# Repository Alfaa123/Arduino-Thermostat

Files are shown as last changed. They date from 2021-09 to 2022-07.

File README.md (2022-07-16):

# Arduino-Thermostat

This is a project to create a Arduino (or Arduino compatible) powered home thermostat. Version 2 PCB schematic and design is complete.

# Electrical Design

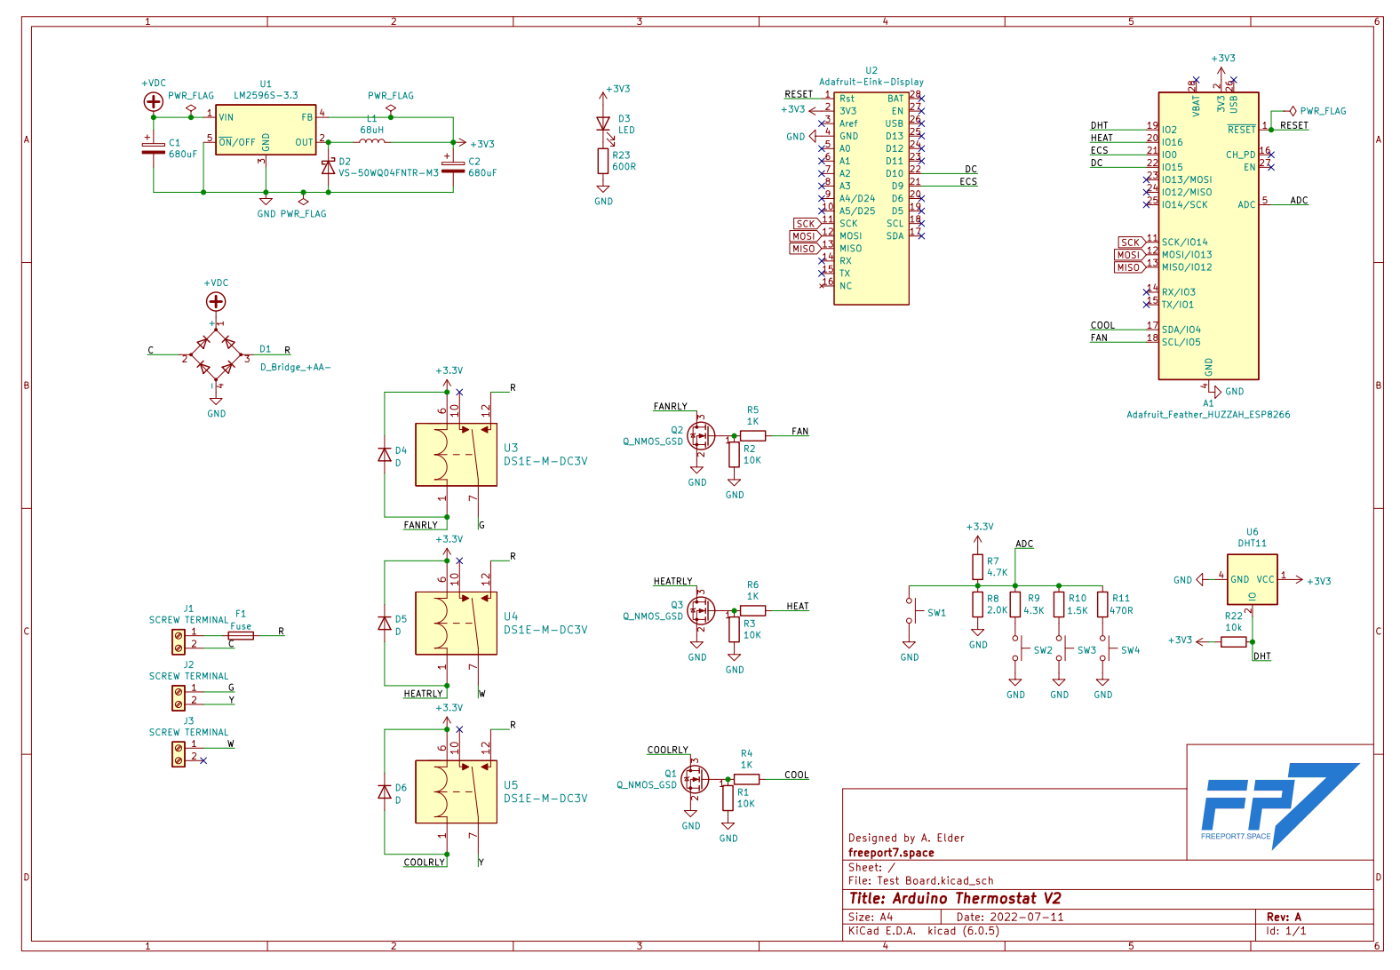
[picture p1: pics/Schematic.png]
Schematic


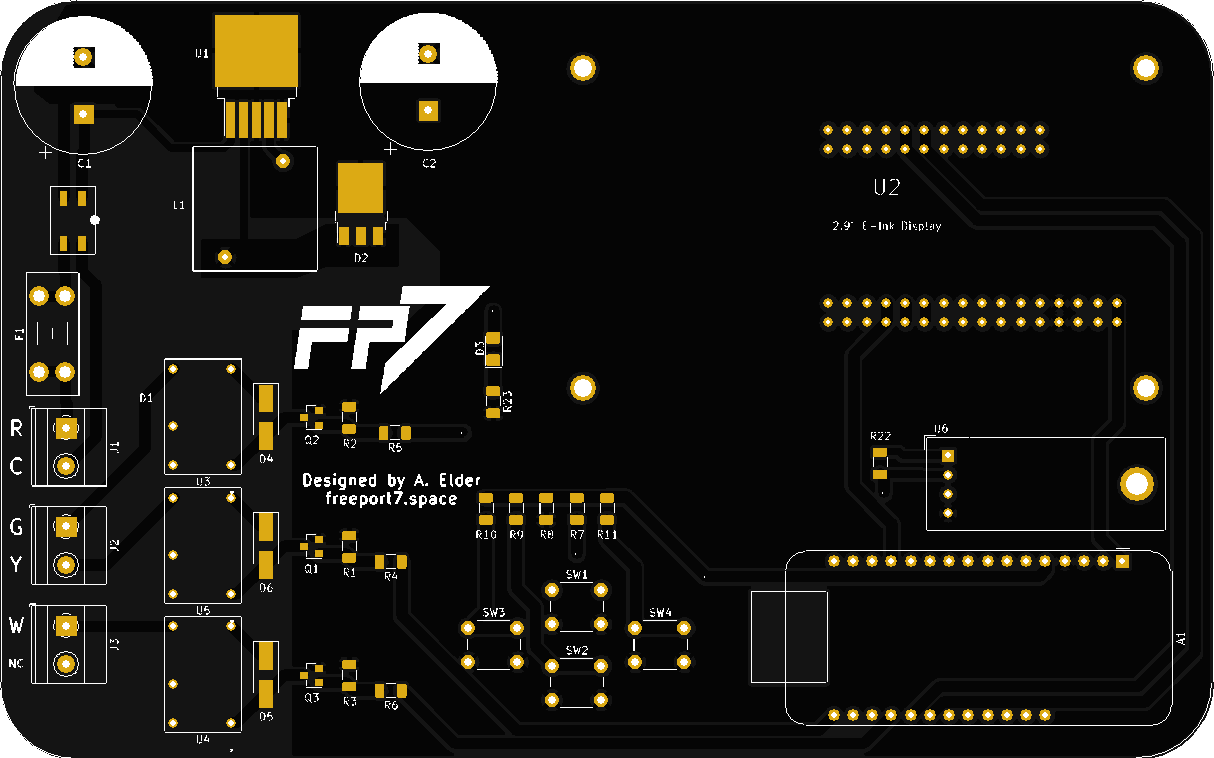
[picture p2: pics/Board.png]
Board


Version 2 has been updated and upgraded to use many SMD components. The board has shrunk, extra protections added and lots of the lessons learned from V1 were implemented as changes to V2.

## Power Section

This takes the 24v AC from the air handler transformer and rectifies it to create a high voltage DC bus. This is then smoothed and an LM2596 is used as a switching regulator to create a 3.3v supply.

Power for the feather is supplied via the 3.3v pin from the onboard voltage regulator.

The regulator can handle up to 3a of current and would be accurately described as "way overkill" for the power requirements of the low voltage section of this board. However, the LM2596 regulators are so simple and easy to effectively use (thanks TI!) that it was worth the extra cost to just have something "easy."

Because the circuitry in the air handler requires the relays to be switched on with the supplied 24v AC, it is routed down the board to supply the common terminal of the three main relays.

## Relay Drive Section

In order to drive the relays, small logic level MOSFETS are utilized with the feather board outputs acting as gate drivers for the three MOSFETs. The current requirements for the selected relays are very low and can easily be sunk by the selected MOSFETs.

## Inputs and Outputs

An Adafruit Feather HUZZAH ESP8266 will be used to run the thermostat. This was selected because it was cheap, easy to work with and included a WiFi stack (allowing for some internet connected thermostat features in the future). One limitation of the ESP8266 is the extremely limited IO compared to the Arduino Nano of the V1 design. This lead to lots of design challanges, including the use of the onboard ADC for ladder buttons to save IO.

The central feature of the V2 design is the inclusion of a 2.9 inch e-ink display instead of a standard LCD. This high resolution, low power display will be ideal for a thermostat as the display needs minimal updates during normal usage.

## Physical Outline

The physical outline of the board was designed to mimic my current thermostat. No mounting holes are included in the V2 design due to the success of the board edge mount that was used on the V1 design.

## Lessons Learned for V2

- ~~Arduino placement needs to be revised. Currently plugging in the USB cable is impossible without bending a cable and potentially damaging the Arduino. This is the biggest mistake.~~ **fixed on V2 design. USB connector points toward the board edge and is easy to access**
- ~~Screw terminal placement needs to be revised. Currently with the massive spacing, it required me to trim a lot of the insulation off of the 5 conductor cable in order to spread the wires out far enough to reach.~~ **fixed on V2 design. Screw terminals were moved much closer together and should make wiring the thermostat much easier**
- ~~More markings on the front of the PCB to show which screw terminal does what. Currently it requires me to open the schematic and board files to correctly wire the thermostat.~~ **fixed on V2 design. Board markings on the silkscreen should make wiring the thermostat much easier.**
- ~~More work should be done to minimize footprint. Currently, the thermostat is physically very large.~~ **fixed on V2 design. Board outline has shrunk to around 60% of the original size.**
- ~~A larger screen would be nice to fit more information. A dot matrix or OLED would be best.~~ **fixed on V2 design. e-ink display selected as high resolution and low power display.**
- ~~Smaller regulator section and relays would go a long way to making the board shrink.~~ **unchanged on V2 design. However, the capacitors were revised with shorter, higher quality parts, the regulator was changed to a surface mount version and the diode and inductor were swapped with physically smaller versions.**

# Programming

No V2 programming has been written yet.

## Required Libraries

TBD once V2 programming is underway

## Planned Future Development

- PID control or other method for better temperature control.
- Humidistat control mode
- Adjustable circ fan frequency
- Better menu system
- Filtering on the temperature sensor to prevent rapid cycling
- Cycling time limit to prevent compressor damage

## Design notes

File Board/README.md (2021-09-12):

# Arduino-Thermostat

This is a project to create a arduino powered home thermostat. Currently the project is in the electrical design stage. Version 1 PCB schematic and design is complete.

# Electrical Design

Schematic

Board

The entire project was designed to be through hole for ease of assembly and troubleshooting. Perhaps in the future, a SMD version with a smaller footprint can be made once the electrical design is finalized.

## Power Section

This takes the 24v AC from the air handler transformer and rectifies it to create a higher voltage DC bus. This is then smoothed and an LM2596 is used as a switching regulator to create a 5.0v supply.

Power for the arduino is supplied via the 5v pin from the onboard voltage regulator.

The regulator can handle upto 3a of current and would be accurately described as "way overkill" for the power requirements of the low voltage section of this board. Once V1 is confirmed to be working, a redesign will be carried out that will allow a lower BOM cost and a physical design shrink.

Because the circuitry in the air handler requires the relays to be switched on with the supplied 24v AC, it is routed down the board to supply the common terminal of the three main relays.

## Relay Driver

A L293D Bipolar Motor Driver was chosen because it was readily available in DIP format, worked for the voltages required, had logic level inputs and had built in flyback diodes that allowed for less physical space usage at the expense of a higher BOM cost.

Additionally, due to the extra available output, the supply for the LCD backlight is switched with output 4.

## Inputs and Outputs

An arduino nano will be used to run the thermostat, ample GPIO meant that each physical button could have it's own DIO pin. Additionally, the LCD was able to be run directly in 4 bit parallel mode allowing for lower BOM cost and simpler electrical design.

The DHT11 may be swapped out with a DHT22 as they have the same footprint and the DHT 22 has a wider range of measurement.

## Physical Outline

The physical outline of the board was designed to mimic my current thermostat. 4 mounting holes were provided to allow for either wall mounting or a case.

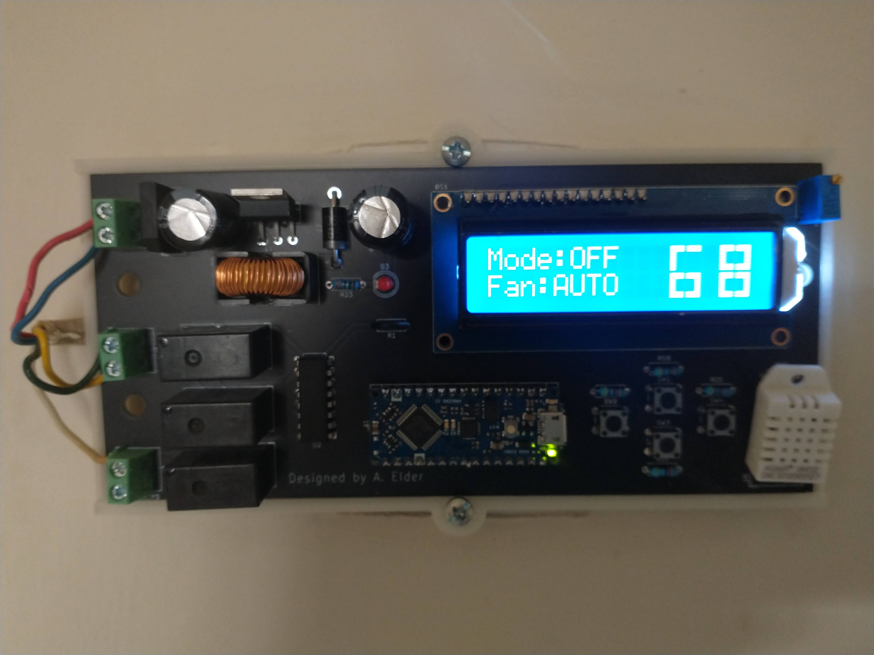
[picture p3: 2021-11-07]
pics/Working.jpg

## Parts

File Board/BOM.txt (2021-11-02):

https://www.digikey.com/en/products/detail/te-connectivity-amp-connectors/796911-3/2223900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

https://www.digikey.com/en/products/detail/te-connectivity-amp-connectors/796911-2/14786015

https://www.digikey.com/en/products/detail/apem-inc/MJTP1230/1798037

https://www.digikey.com/en/products/detail/microchip-technology/lm2575-5-0bt/1027650

https://www.digikey.com/en/products/detail/bourns-inc/2100LL-331-H-RC/725965

https://www.digikey.com/en/products/detail/stmicroelectronics/STPS5L60/2864639

https://www.digikey.com/en/products/detail/panasonic-electronic-components/EEU-FC1C101H/6109530

https://www.digikey.com/en/products/detail/panasonic-electronic-components/EEU-FC1H221B/6109552

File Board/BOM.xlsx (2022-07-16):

Description | Qty | Link
Relay | 3 | https://www.digikey.com/en/products/detail/panasonic-electric-works/DS1E-S-DC3V/413288
2 Position Screw Terminal | 3 | https://www.digikey.com/en/products/detail/phoenix-contact/5442206/4390264
Voltage Regulator | 1 | https://www.digikey.com/en/products/detail/texas-instruments/LM2596S-3-3/3701219
Input/Output Cap | 2 | https://www.digikey.com/en/products/detail/panasonic-electronic-components/EEU-FC1J681S/356177
Schottky Diode | 1 | https://www.digikey.com/en/products/detail/vishay-general-semiconductor-diodes-division/VS-50WQ04FNTR-M3/4933731
Inductor 68 uH | 1 | https://www.digikey.com/en/products/detail/pulse-electronics-power/PE-53830NL/2266003
5mm LED | 1 | Sourced Locally
220R 1/4w THT Resistor | 4 | Sourced Locally
10K 1/4w THT Resistor | 4 | Sourced Locally
Rectifier | 1 | https://www.digikey.com/en/products/detail/smc-diode-solutions/KMB26S/7898343
Logic Level FET | 3 | https://www.digikey.com/en/products/detail/infineon-technologies/BSS806NH6327XTSA1/2783472
Header Pins for Display | 2 | https://www.digikey.com/en/products/detail/amphenol-cs-fci/67996-416HLF/1878538
16 Pin Header For Feather | 1 | https://www.digikey.com/en/products/detail/sullins-connector-solutions/PPTC161LFBN-RC/810154
12 Pin Header For Feather | 1 | https://www.digikey.com/en/products/detail/sullins-connector-solutions/PPTC121LFBN-RC/807231
e-Ink Display | 1 | https://www.adafruit.com/product/4777
MCU | 2 | https://www.adafruit.com/product/2821
Flyback Diodes | 3 | https://www.digikey.com/en/products/detail/smc-diode-solutions/S1G/6022594
LED | 1 | https://www.digikey.com/en/products/detail/everlight-electronics-co-ltd/QTLP650D4TR/2675910
Buttons | 4 | https://www.digikey.com/en/products/detail/cui-devices/TS02-66-60-BK-160-SCR-D/15634259
Fuse Holder | 1 | https://www.digikey.com/en/products/detail/keystone-electronics/3568/2137306
Fuse | 1 | https://www.digikey.com/en/products/detail/eaton-bussmann-electrical-division/BK-ATM-3/264847

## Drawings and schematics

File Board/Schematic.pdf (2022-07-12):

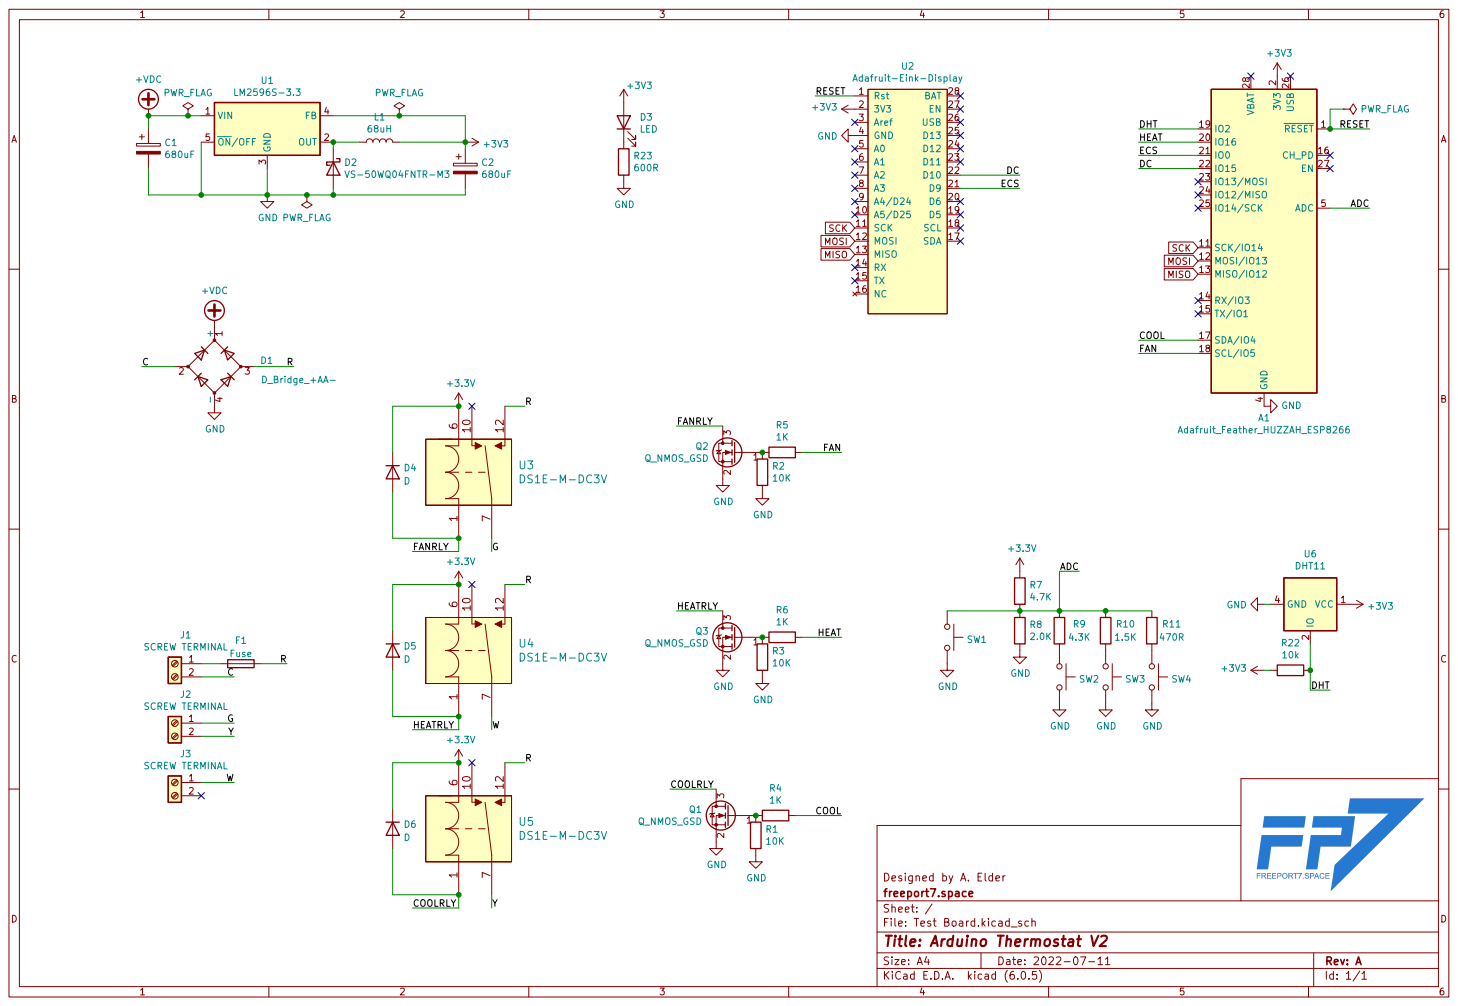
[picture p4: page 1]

2 GND 4 U6 DHT11 D2VS-50WQ04FNTR-M3 ~{RESET} 1 SCK/IO14 11 MOSI/IO13 12 MISO/IO12 13 RX/IO3 14 TX/IO1 15 CH_PD 16 SDA/IO4 17 SCL/IO5 18

SCK MOSI SCK MOSI MISO

File: Test Board.kicad_sch Sheet: / freeport7.space

Id: 1/1 Title: Arduino Thermostat V2

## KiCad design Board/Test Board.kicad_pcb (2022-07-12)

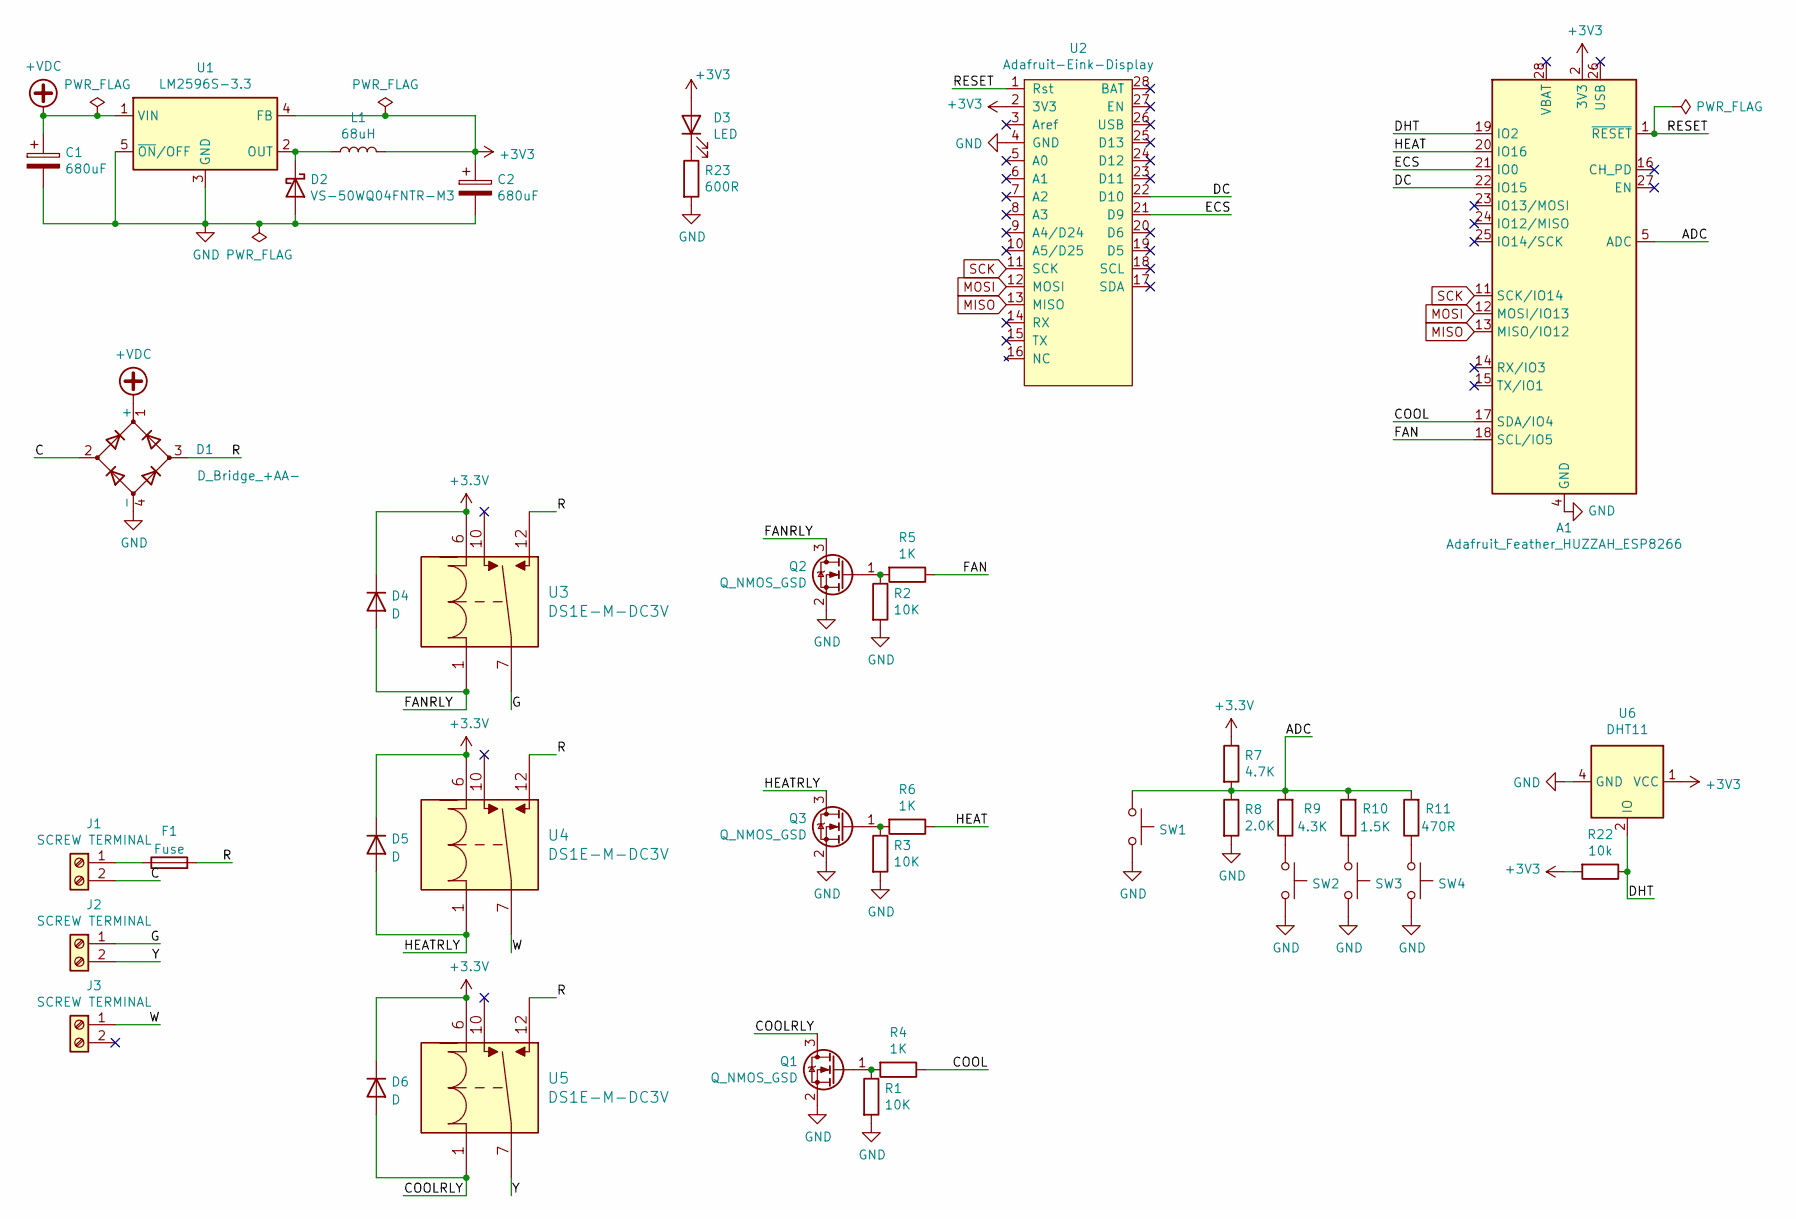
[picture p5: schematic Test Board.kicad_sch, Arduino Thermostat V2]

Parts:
A1: Adafruit_Feather_HUZZAH_ESP8266; Adafruit_Feather
C1, C2: 680uF; CP_Radial_D18.0mm_P7.50mm
D1: D_Bridge_+AA-; Diode Bridge 4-SMD
D2: VS-50WQ04FNTR-M3; TO-252-3_TabPin2
D3: LED; LED_1206_3216Metric_Pad1.42x1.75mm_HandSolder
D4, D5, D6: D; D_SMA_Handsoldering
F1: Fuse; Fuseholder_Blade_Mini_Keystone_3568
J1, J2, J3: SCREW TERMINAL; TerminalBlock_Phoenix_MKDS-1,5-2-5.08_1x02_P5.08mm_Horizont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
L1: 68uH; L_Radial_L16.1mm_W16.1mm_Px7.62mm_Py12.70mm_Pulse_LP-44
Q1, Q2, Q3: Q_NMOS_GSD; SOT-23
R1, R2, R3: 10K; R_1206_3216Metric
R4, R5, R6: 1K; R_1206_3216Metric
R7: 4.7K; R_1206_3216Metric
R8: 2.0K; R_1206_3216Metric
R9: 4.3K; R_1206_3216Metric
R10: 1.5K; R_1206_3216Metric
R11: 470R; R_1206_3216Metric
R22: 10k; R_1206_3216Metric
R23: 600R; R_1206_3216Metric
SW1, SW2, SW3, SW4: SW_Push; SW_PUSH_6mm_H5mm
U1: LM2596S-3.3; TO-263-5_TabPin3
U2: Adafruit-Eink-Display; Adafruit-eink-display
U3, U4, U5: DS1E-M-DC3V; DS1E-M-DC5V
U6: DHT11; DHT22-Horizontal

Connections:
+VDC: C1.1, D1.1 (+), U1.1 (VIN)
/ADC: A1.5 (ADC), R7.2, R8.1, R9.2, R10.2, R11.2, SW1.1
/C: D1.2, J1.2
/COOL: A1.17 (SDA/IO4), R4.1
/COOLRLY: D6.2 (A), Q1.3 (D), U5.1
/DC: A1.22 (IO15), U2.22 (D10)
/DHT: A1.19 (IO2), R22.1, U6.2 (IO)
/ECS: A1.21 (IO0), U2.21 (D9)
/FAN: A1.18 (SCL/IO5), R5.1
/FANRLY: D4.2 (A), Q2.3 (D), U3.1
/G: J2.1, U3.7
/HEAT: A1.20 (IO16), R6.1
/HEATRLY: D5.2 (A), Q3.3 (D), U4.1
/R: D1.3, F1.2, U3.12, U4.12, U5.12
/RESET: A1.1 (~RESET), U2.1 (Rst)
/W: J3.1, U4.7
/Y: J2.2, U5.7
GND: A1.4 (GND), C1.2, C2.2, D1.4 (-), D2.2 (A), Q1.2 (S), Q2.2 (S), Q3.2 (S), R1.2, R2.2, R3.2, R8.2, R23.2, SW1.2, SW2.2, SW3.2, SW4.2, U1.3 (GND), U1.5 (~ON/OFF), U2.4 (GND), U6.4 (GND)
MISO: A1.13 (MISO/IO12), U2.13 (MISO)
MOSI: A1.12 (MOSI/IO13), U2.12 (MOSI)
unnamed: D2.1 (K), L1.1, U1.2 (OUT)
unnamed: D3.1 (K), R23.1
unnamed: F1.1, J1.1
unnamed: Q1.1 (G), R1.1, R4.2
unnamed: Q2.1 (G), R2.1, R5.2
unnamed: Q3.1 (G), R3.1, R6.2
unnamed: R9.1, SW2.1
unnamed: R10.1, SW3.1
unnamed: R11.1, SW4.1
SCK: A1.11 (SCK/IO14), U2.11 (SCK)

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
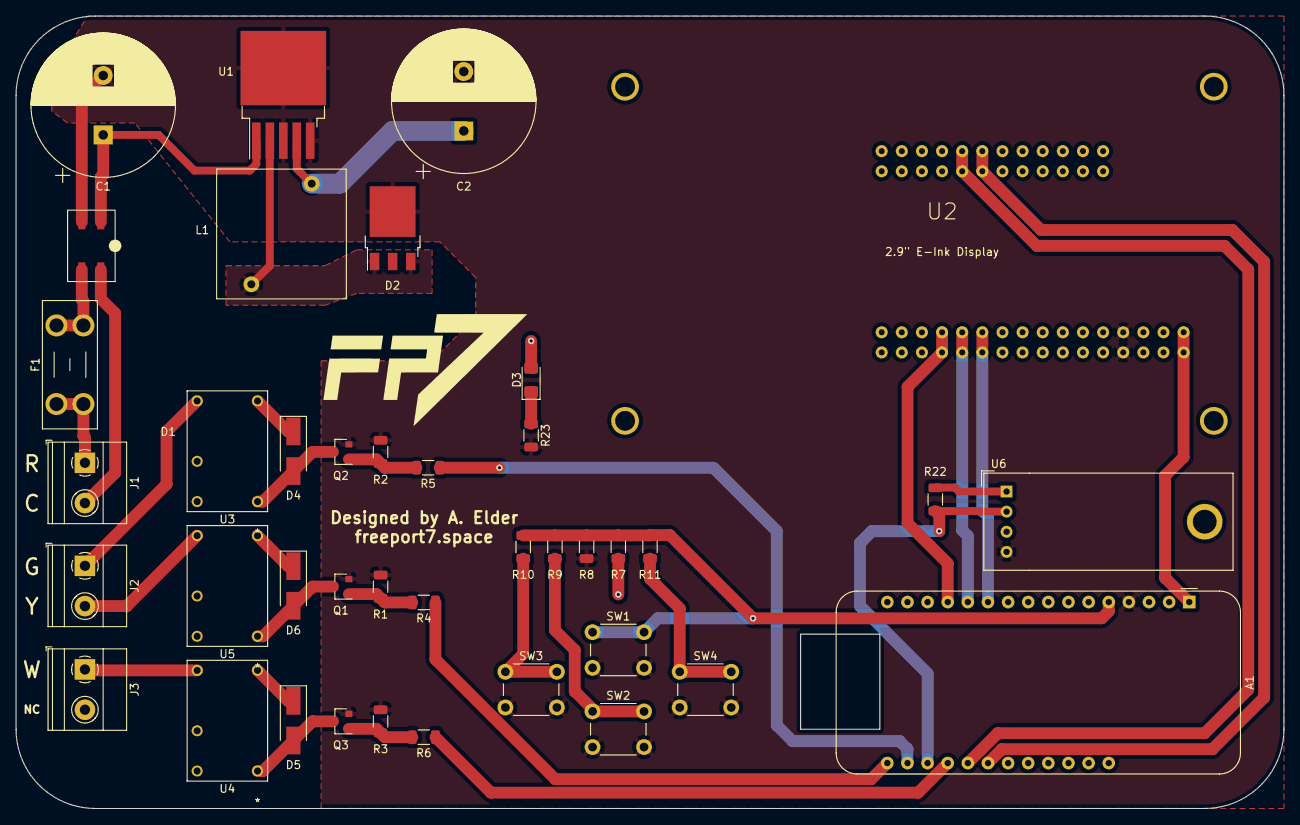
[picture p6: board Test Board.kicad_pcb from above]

Board: 2 copper layers, 160.0 x 100.0 mm, 40 parts (0 on the bottom side), 31 nets.

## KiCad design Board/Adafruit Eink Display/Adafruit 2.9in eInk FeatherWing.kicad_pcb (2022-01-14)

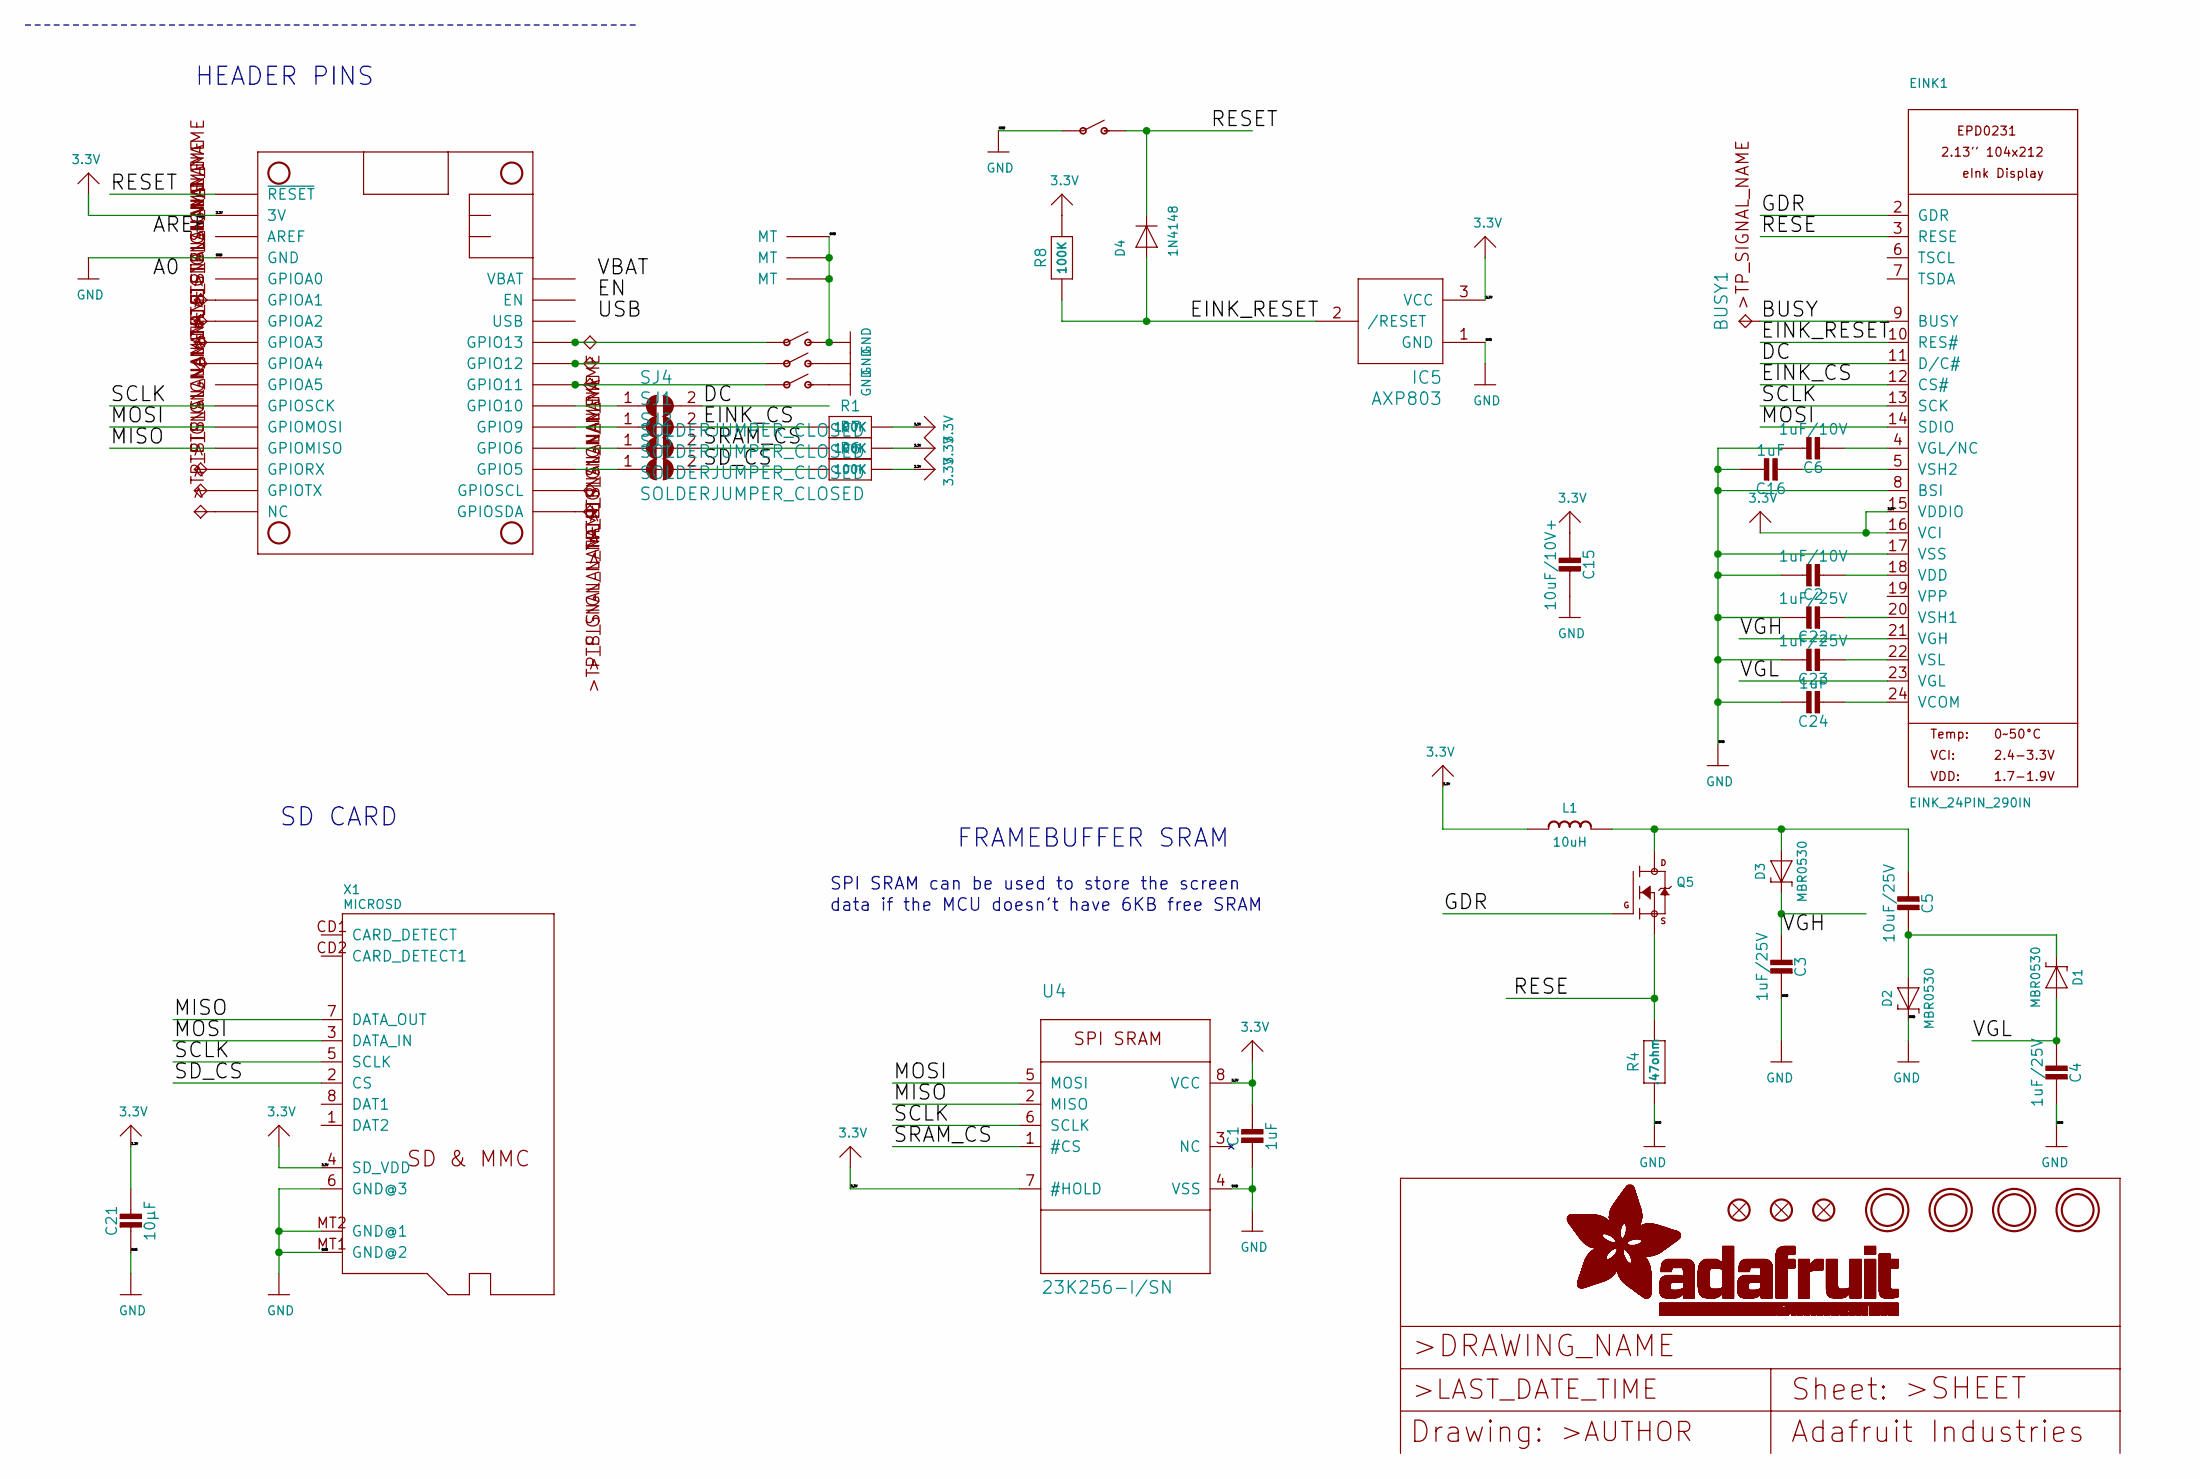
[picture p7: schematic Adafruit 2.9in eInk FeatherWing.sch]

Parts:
BUSY1: TPTP15SQ; TP15SQ
C1: 1uF; 0805_10MGAP
C2, C6: 1uF/10V; 0805-NO
C3, C4, C22, C23: 1uF/25V; 0805-NO
C5: 10uF/25V; 0805-NO
C15: 10uF/10V+; 0805-NO
C16, C24: 1uF; 0805-NO
C21: 10µF; 0805-NO
D1, D2, D3: MBR0530; SOD-123
D4: 1N4148; SOD-323F
EINK1: EINK_24PIN_290IN; EINK_290IN
FID1, FID2, FID3: FIDUCIAL_1MM
IC5: AXP803; SOT23
L1: 10uH; INDUCTOR_4X4MM_NR401
MS1: FEATHERWING_SMTDUALNOHOLES; FEATHERWING_SMT_NOHOLES
Q5: IRLML0100; SOT23-3
R1, R6, R7, R8: 100K; 0603-NO
R4: .47ohm; 0805_10MGAP
SJ1, SJ2, SJ3, SJ4: SOLDERJUMPER_CLOSED; SOLDERJUMPER_CLOSEDWIRE
SW1, SW2, SW3, SW4: SWITCH_SPST_TACT_RA; SPST_TACTILE_RA
TP1, TP2, TP3, TP4, TP5, TP6, TP7, TP8, TP9, TP11, TP12, TP13: TPTP15SQ; TP15SQ
U4: 23K256-I/SN; SOIC8_150MIL
U$3, U$4, U$5, U$6: MOUNTINGHOLE2.5; MOUNTINGHOLE_2.5_PLATED
X1: MICROSD

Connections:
3.3V: C1.1, C15.2, C21.1, EINK1.15 (VDDIO), EINK1.16 (VCI), IC5.3 (VCC), L1.P$2 (2), MS1.2 (3V), MS1.2B (3V), R1.2, R6.2, R7.2, R8.2, U4.7 (#HOLD), U4.8 (VCC), X1.4 (SD_VDD)
/BUSY: BUSY1.TP, EINK1.9 (BUSY)
/DC: EINK1.11 (D/C#), SJ4.2
/EINK_CS: EINK1.12 (CS#), R1.1, SJ1.2
/EINK_RESET: D4.A, EINK1.10 (RES#), IC5.2 (/RESET), R8.1
/GDR: EINK1.2 (GDR), Q5.1 (G)
/MISO: MS1.13 (GPIOMISO), MS1.13B (GPIOMISO), U4.2 (MISO), X1.7 (DATA_OUT)
/MOSI: EINK1.14 (SDIO), MS1.12 (GPIOMOSI), MS1.12B (GPIOMOSI), U4.5 (MOSI), X1.3 (DATA_IN)
/RESE: EINK1.3 (RESE), Q5.2 (S), R4.1
/RESET: D4.C, MS1.1 (~RESET), MS1.1B (~RESET), SW3.2 (S)
/SCLK: EINK1.13 (SCK), MS1.11 (GPIOSCK), MS1.11B (GPIOSCK), U4.6 (SCLK), X1.5 (SCLK)
/SD_CS: R6.1, SJ3.2, X1.2 (CS)
/SRAM_CS: R7.1, SJ2.2, U4.1 (#CS)
/VGH: C3.1, D3.C, EINK1.21 (VGH)
/VGL: C4.1, D1.A, EINK1.23 (VGL)
GND: C1.2, C2.1, C3.2, C4.2, C6.1, C15.1, C16.1, C21.2, C22.1, C23.1, C24.1, D2.C, EINK1.8 (BSI), EINK1.17 (VSS), IC5.1 (GND), MS1.4 (GND), MS1.4B (GND), R4.2, SW1.2 (S), SW1.MT1 (MT), SW1.MT2 (MT), SW2.2 (S), SW2.MT1 (MT), SW2.MT2 (MT), SW3.1, SW4.2 (S), SW4.MT1 (MT), SW4.MT2 (MT), U4.4 (VSS), X1.6 (GND@3), X1.MT1 (GND@2), X1.MT2 (GND@1)
unnamed: C2.2, EINK1.18 (VDD)
unnamed: C5.1, D3.A, L1.P$1 (1), Q5.3 (D)
unnamed: C5.2, D1.C, D2.A
unnamed: C6.2, EINK1.4 (VGL/NC)
unnamed: C16.2, EINK1.5 (VSH2)
unnamed: C22.2, EINK1.20 (VSH1)
unnamed: C23.2, EINK1.22 (VSL)
unnamed: C24.2, EINK1.24 (VCOM)
unnamed: MS1.3 (AREF), MS1.3B (AREF)
unnamed: MS1.5 (GPIOA0), MS1.5B (GPIOA0)
unnamed: MS1.6 (GPIOA1), MS1.6B (GPIOA1), TP6.TP
unnamed: MS1.7 (GPIOA2), MS1.7B (GPIOA2), TP7.TP
unnamed: MS1.8 (GPIOA3), MS1.8B (GPIOA3), TP8.TP
unnamed: MS1.9 (GPIOA4), MS1.9B (GPIOA4), TP9.TP
unnamed: MS1.10 (GPIOA5), MS1.10B (GPIOA5)
unnamed: MS1.14 (GPIORX), MS1.14B (GPIORX), TP11.TP
unnamed: MS1.15 (GPIOTX), MS1.15B (GPIOTX), TP12.TP
unnamed: MS1.16 (NC), MS1.16B (NC), TP13.TP
unnamed: MS1.17 (GPIOSDA), MS1.17B (GPIOSDA), TP4.TP
unnamed: MS1.18 (GPIOSCL), MS1.18B (GPIOSCL), TP3.TP
unnamed: MS1.19 (GPIO5), MS1.19B (GPIO5), SJ3.1
unnamed: MS1.20 (GPIO6), MS1.20B (GPIO6), SJ2.1
unnamed: MS1.21 (GPIO9), MS1.21B (GPIO9), SJ1.1
unnamed: MS1.22 (GPIO10), MS1.22B (GPIO10), SJ4.1
unnamed: MS1.23 (GPIO11), MS1.23B (GPIO11), SW1.1, TP1.TP
unnamed: MS1.24 (GPIO12), MS1.24B (GPIO12), SW2.1, TP2.TP
unnamed: MS1.25 (GPIO13), MS1.25B (GPIO13), SW4.1, TP5.TP
unnamed: MS1.26 (USB), MS1.26B (USB)
unnamed: MS1.27 (EN), MS1.27B (EN)
unnamed: MS1.28 (VBAT), MS1.28B (VBAT)

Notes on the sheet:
HEADER PINS
FRAMEBUFFER SRAM
SPI SRAM can be used to store the screen
data if the MCU doesn't have 6KB free SRAM
SD CARD

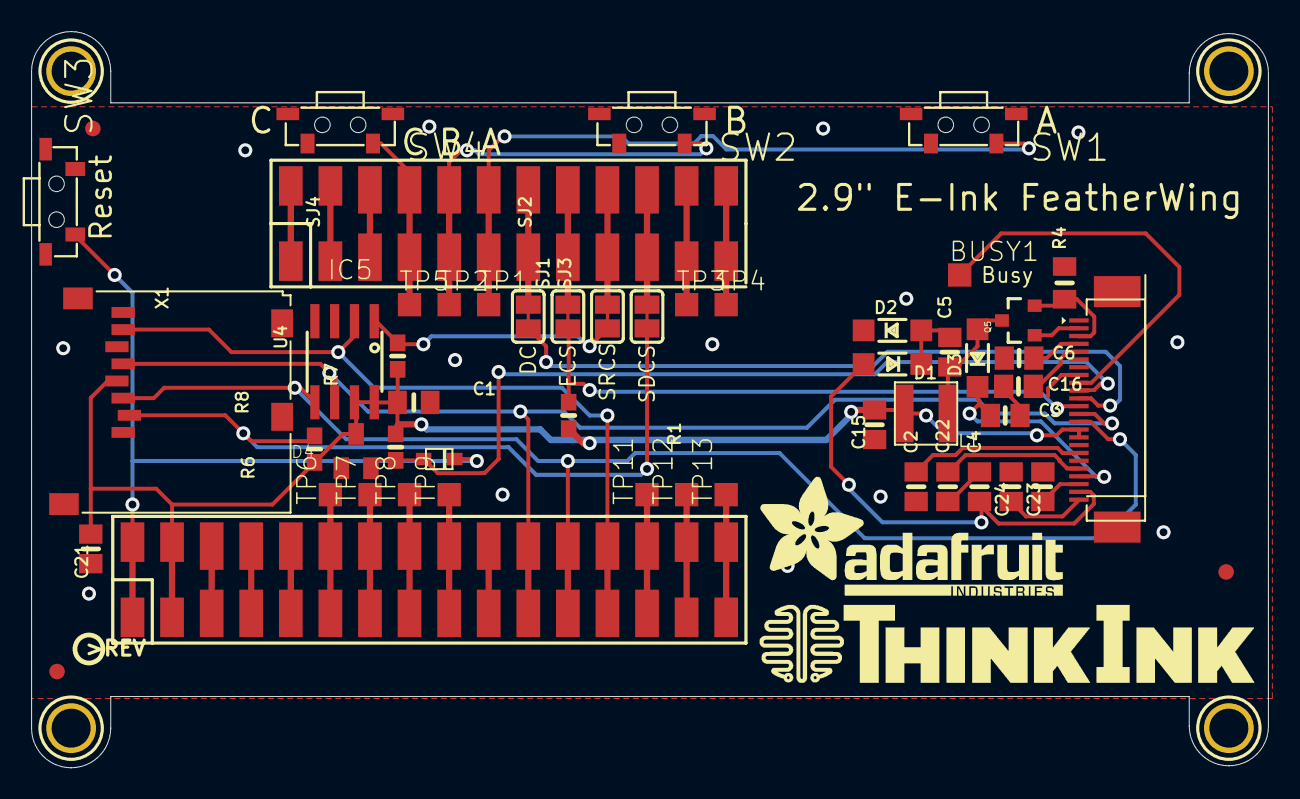
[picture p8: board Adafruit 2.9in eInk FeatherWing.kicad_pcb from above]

Board: 2 copper layers, 79.4 x 47.2 mm, 59 parts (0 on the bottom side), 46 nets.

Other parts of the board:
U$8: THINKINK_1.25IN
U$9: PCBFEAT-REV-040
U$17: ADAFRUIT_TEXT_20MM

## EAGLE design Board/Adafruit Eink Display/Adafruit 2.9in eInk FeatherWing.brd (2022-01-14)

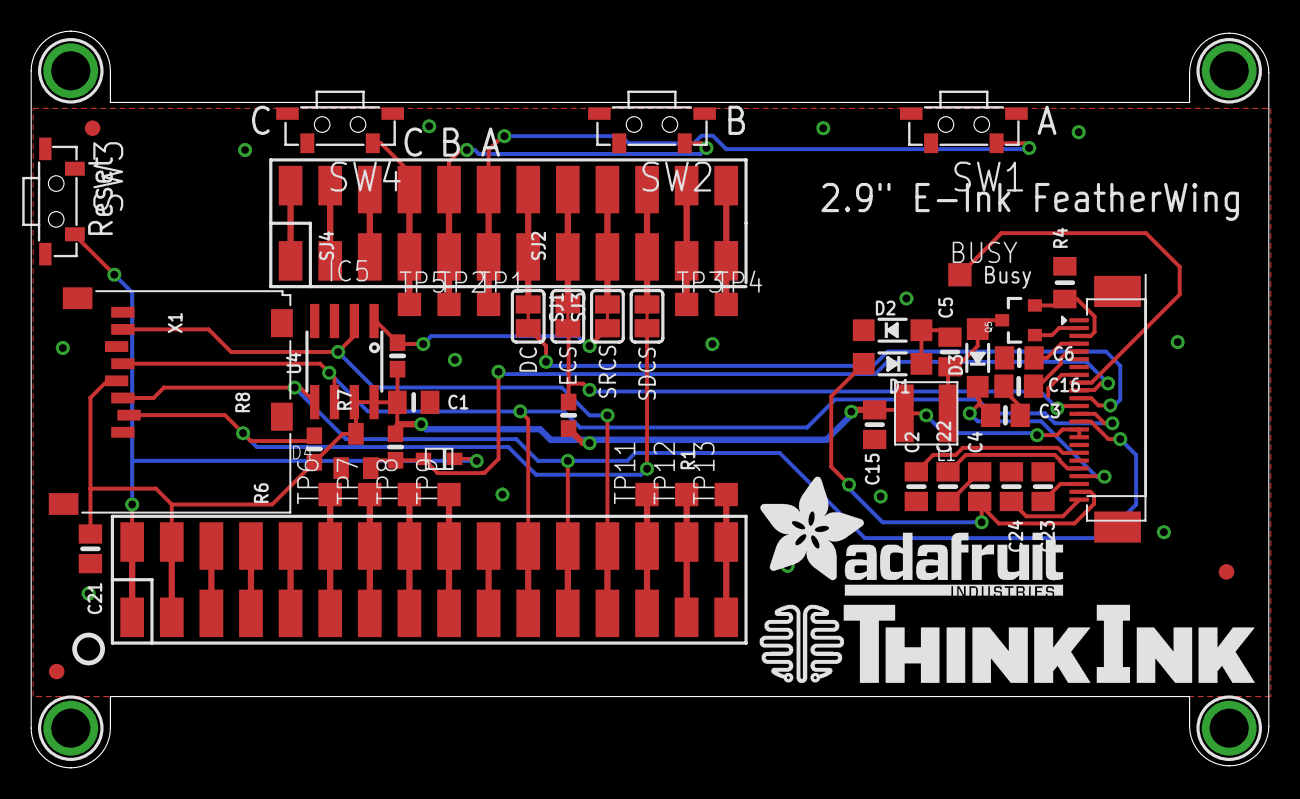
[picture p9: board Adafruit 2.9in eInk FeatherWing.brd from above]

Board: 2 copper layers, 79.4 x 47.2 mm, 59 parts (1 on the bottom side), 46 nets.

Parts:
BUSY: TPTP15SQ; TP15SQ
C1: 1uF; 0805_10MGAP
C2, C6: 1uF/10V; 0805-NO
C3, C4, C22, C23: 1uF/25V; 0805-NO
C5: 10uF/25V; 0805-NO
C15: 10uF/10V+; 0805-NO
C16, C24: 1uF; 0805-NO
C21: 10µF; 0805-NO
D1, D2, D3: MBR0530; SOD-123
D4: 1N4148; SOD-323F
EINK1: EINK_24PIN_290IN; EINK_290IN
FID1, FID2, FID3: FIDUCIAL_1MM
IC5: AXP803; SOT23
L1: 10uH; INDUCTOR_4X4MM_NR401
MS1: FEATHERWING_SMTDUALNOHOLES; FEATHERWING_SMT_NOHOLES
Q5: IRLML0100; SOT23-3
R1, R6, R7, R8: 100K; 0603-NO
R4: .47ohm; 0805_10MGAP
SJ1, SJ2, SJ3, SJ4: SOLDERJUMPER_CLOSEDWIRE
SW1, SW2, SW3, SW4: SPST_TACTILE_RA
TP1, TP2, TP3, TP4, TP5, TP6, TP7, TP8, TP9, TP11, TP12, TP13: TPTP15SQ; TP15SQ
U4: 23K256-I/SN; SOIC8_150MIL
U$3, U$4, U$5, U$6: MOUNTINGHOLE2.5; MOUNTINGHOLE_2.5_PLATED
U$8: THINKINK_1.25IN
U$9: PCBFEAT-REV-040
U$17: ADAFRUIT_TEXT_20MM
X1: MICROSD

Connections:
3.3V: C1.1, C15.2, C21.1, EINK1.15, EINK1.16, IC5.3, L1.P$2, MS1.2, MS1.2B, R1.2, R6.2, R7.2, R8.2, U4.7, U4.8, X1.4
A0: MS1.5, MS1.5B
AREF: MS1.3, MS1.3B
BUSY: BUSY.TP, EINK1.9
DC: EINK1.11, SJ4.2
EINK_CS: EINK1.12, R1.1, SJ1.2
EINK_RESET: D4.A, EINK1.10, IC5.2, R8.1
EN: MS1.27, MS1.27B
GDR: EINK1.2, Q5.1
GND: C1.2, C2.1, C3.2, C4.2, C6.1, C15.1, C16.1, C21.2, C22.1, C23.1, C24.1, D2.C, EINK1.8, EINK1.17, IC5.1, MS1.4, MS1.4B, R4.2, SW1.2, SW1.MT1, SW1.MT2, SW2.2, SW2.MT1, SW2.MT2, SW3.1, SW4.2, SW4.MT1, SW4.MT2, U4.4, X1.6, X1.MT1, X1.MT2
H: MS1.19, MS1.19B, SJ3.1
I: MS1.20, MS1.20B, SJ2.1
J: MS1.21, MS1.21B, SJ1.1
K: MS1.22, MS1.22B, SJ4.1
MISO: MS1.13, MS1.13B, U4.2, X1.7
MOSI: EINK1.14, MS1.12, MS1.12B, U4.5, X1.3
unnamed: MS1.10, MS1.10B
unnamed: C5.2, D1.C, D2.A
unnamed: C5.1, D3.A, L1.P$1, Q5.3
unnamed: C16.2, EINK1.5
unnamed: C2.2, EINK1.18
unnamed: C22.2, EINK1.20
unnamed: MS1.6, MS1.6B, TP6.TP
unnamed: C6.2, EINK1.4
unnamed: MS1.7, MS1.7B, TP7.TP
unnamed: MS1.8, MS1.8B, TP8.TP
unnamed: MS1.9, MS1.9B, TP9.TP
unnamed: MS1.14, MS1.14B, TP11.TP
unnamed: MS1.15, MS1.15B, TP12.TP
unnamed: MS1.16, MS1.16B, TP13.TP
unnamed: MS1.17, MS1.17B, TP4.TP
unnamed: MS1.18, MS1.18B, TP3.TP
unnamed: MS1.23, MS1.23B, SW1.1, TP1.TP
unnamed: MS1.24, MS1.24B, SW2.1, TP2.TP
unnamed: MS1.25, MS1.25B, SW4.1, TP5.TP
unnamed: C23.2, EINK1.22
unnamed: C24.2, EINK1.24
RESE: EINK1.3, Q5.2, R4.1
RESET: D4.C, MS1.1, MS1.1B, SW3.2
SCLK: EINK1.13, MS1.11, MS1.11B, U4.6, X1.5
SD_CS: R6.1, SJ3.2, X1.2
SRAM_CS: R7.1, SJ2.2, U4.1
USB: MS1.26, MS1.26B
VBAT: MS1.28, MS1.28B
VGH: C3.1, D3.C, EINK1.21
VGL: C4.1, D1.A, EINK1.23

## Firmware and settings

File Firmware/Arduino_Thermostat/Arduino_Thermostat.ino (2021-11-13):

#define backlight_pin 10

#define UP_PIN 6
#define DOWN_PIN 7
#define LEFT_PIN 8
#define RIGHT_PIN 9

#define MAX_MENU_ITEMS 3

#define FAN 3
#define HEAT 4
#define COOL 5

#define HEATING 2
#define COOLING 1

#define CIRC_INTERVAL 1200000

#define LCD_TIMEOUT 10000

#define TEMP_HYSTERESIS 1

#include <AceButton.h>
using namespace ace_button;
#include <LiquidCrystal.h>
#include <BigNums2x2.h>
#include "DHT.h"

void backlight(bool);
void handleButtonEvent(AceButton*, uint8_t, uint8_t);

AceButton buttonUp(UP_PIN);
AceButton buttonDown(DOWN_PIN);
AceButton buttonLeft(LEFT_PIN);
AceButton buttonRight(RIGHT_PIN);

int humidity;
int temperatureArray[3];
int temperature;
char tempIndex = 0;
int setpoint = 75;
bool tempAdjustment = 0;
bool circFanInterval = 0;
bool backlightStatus = 0;
char mode = 0;
char fan = 0;
char menu = 0;
long double updateLCDOldMillis;
long double circFanOldMillis;
long double LCDTimeoutOldMillis;

LiquidCrystal lcd(A1, A0, A5, A4, A3, A2);
DHT dht(2, DHT22);
BigNums2x2 bigNum(TREK);
// the setup function runs once when you press reset or power the board
void setup() {
  pinMode(UP_PIN, INPUT);
  pinMode(DOWN_PIN, INPUT);
  pinMode(LEFT_PIN, INPUT);
  pinMode(RIGHT_PIN, INPUT);

  pinMode(FAN, OUTPUT);
  pinMode(HEAT, OUTPUT);
  pinMode(COOL, OUTPUT);

  ButtonConfig* buttonConfig = ButtonConfig::getSystemButtonConfig();
  buttonConfig->setEventHandler(handleButtonEvent);
  buttonConfig->setFeature(ButtonConfig::kFeatureClick);


  //Serial.begin(9600);
  pinMode(backlight_pin, OUTPUT);
  lcd.begin(16, 2);
  dht.begin();
  for (int x=0;x<3;x++){
  temperatureArray[x] = dht.readTemperature(true);
  }
  backlight(1);
  LCDTimeoutOldMillis = millis();
}

// the loop function runs over and over again forever
void loop() {
  buttonUp.check();
  buttonDown.check();
  buttonLeft.check();
  buttonRight.check();

if  (millis() - LCDTimeoutOldMillis > LCD_TIMEOUT){
  backlight(0);
  menu = 0;
}
else {backlight(1);}
  
  if (millis() - updateLCDOldMillis > 10000) {
    updateDHT();
    printTemp();
    printMenu(menu);
    updateTempControl();
    updateFanControl();
    updateLCDOldMillis = millis();
  }
}

void backlight(bool direction) {
  if (backlightStatus ^ direction){
  for (int x = 0; x < 255; x++) {
    delay(2);
    if (direction) {
      backlightStatus = 1;
      analogWrite(10, x);
    }
    else {
      backlightStatus = 0;
      analogWrite(10, 260 - x);
    }
  }
  }

}

void printTemp() {
  bigNum.print(temperature, 2, 11, ' ');
}

void updateDHT() {
  temperatureArray[tempIndex] = dht.readTemperature(true);
  tempIndex++;
  if (tempIndex > 2){tempIndex = 0;}
  temperature = ((temperatureArray[0] + temperatureArray[1] + temperatureArray[2])/3);
  humidity = dht.readHumidity();
}

void printMenu(char menuNum) {
  lcd.setCursor(0, 0);
  printMenuItem(menuNum);
  lcd.setCursor(0, 1);
  if (menuNum < MAX_MENU_ITEMS) {
    printMenuItem(menuNum + 1);
  }
  else {
    lcd.print("Ver. 0.8 ");
    //printMenuItem(0);
  }
}

void printMenuItem(char itemNum) {
  switch (itemNum) {
    case 0:
      lcd.print("Humid:");
      lcd.print(humidity);
      lcd.print("% ");
      break;
    case 1:
      lcd.print("Setpt:");
      if (mode == 0){lcd.print("OFF");}
      else if (mode == COOLING){lcd.print("C");
      lcd.print(setpoint);}
      else if (mode == HEATING){lcd.print("H");
      lcd.print(setpoint);}
      lcd.print(" ");
      break;
    case 2:
      lcd.print("Mode:");
      switch (mode) {
        case 0:
          lcd.print("OFF ");
          break;
        case COOLING:
          lcd.print("COOL");
          break;
        case HEATING:
          lcd.print("HEAT");
          break;
      }
      break;
    case 3:
      lcd.print("Fan:");
      switch (fan) {
        case 0:
          lcd.print("AUTO ");
          break;
        case 1:
          lcd.print("ON   ");
          break;
        case 2:
          lcd.print("CIRC ");
          break;
      }
      break;
  }
}

void updateTempControl() {
  switch (mode) {
    case 0:
      digitalWrite(HEAT, LOW);
      digitalWrite(COOL, LOW);
      tempAdjustment = 0;
      break;
    case COOLING:
      if (setpoint < temperature - TEMP_HYSTERESIS) {
        tempAdjustment = 1;
        digitalWrite(COOL, HIGH);
      }
      else if (setpoint > temperature + TEMP_HYSTERESIS) {
        tempAdjustment = 0;
        digitalWrite(COOL, LOW);
      }
      break;
    case HEATING:
      if (setpoint > temperature + TEMP_HYSTERESIS) {
        tempAdjustment = 1;
        digitalWrite(HEAT, HIGH);
      }
      else if (setpoint < temperature - TEMP_HYSTERESIS) {
        tempAdjustment = 0;
        digitalWrite(HEAT, LOW);
      }
      break;
  }
}

void updateFanControl() {
  switch (fan) {
      if (tempAdjustment) {
        digitalWrite(FAN, HIGH);
      }
      else {
      case 0:
        digitalWrite(FAN, LOW);
        circFanInterval = 0;
        break;
      case 1:
        digitalWrite(FAN, HIGH);
        circFanInterval = 0;
        break;
      case 2:
        if (millis() - circFanOldMillis > CIRC_INTERVAL) {
          circFanInterval = !circFanInterval;
          circFanOldMillis = millis();
        }
        digitalWrite(FAN, circFanInterval);
        break;
      }
  }


}

void handleButtonEvent(AceButton* button, uint8_t eventType, uint8_t buttonState) {

LCDTimeoutOldMillis = millis();

  switch (eventType) {
    case AceButton::kEventPressed:
      break;
    case AceButton::kEventReleased:
      break;
    case AceButton::kEventClicked:
      switch (button->getPin()) {
        case UP_PIN:
          menu = menu - 1;
          if (menu < 0) {
            menu = 0;
          }
          printMenu(menu);
          break;
        case DOWN_PIN:
          menu++;
          if (menu > MAX_MENU_ITEMS) {
            menu = MAX_MENU_ITEMS;
          }
          printMenu(menu);
          break;
        case LEFT_PIN:
          switch (menu) {
            case 0:
              break;
            case 1:
              setpoint--;
              if (setpoint < 50) {
                setpoint = 50;
              }
              break;
            case 2:
              mode--;
              if (mode < 0) {
                mode = 0;
              }
              break;
            case 3:
              fan--;
              if (fan < 0) {
                fan = 0;
              }
              break;
          }
          printMenu(menu);
          break;
        case RIGHT_PIN:
          switch (menu) {
            case 0:
              break;
            case 1:
              setpoint++;
              if (setpoint > 90) {
                setpoint = 90;
              }
              break;
            case 2:
              mode++;
              if (mode > 2) {
                mode = 2;
              }
              break;
            case 3:
              fan++;
              if (fan > 2) {
                fan = 2;
              }
              break;
          }
          printMenu(menu);
          break;


      }
      break;
  }
}

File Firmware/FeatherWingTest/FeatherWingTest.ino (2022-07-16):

/***************************************************
  Adafruit invests time and resources providing this open source code,
  please support Adafruit and open-source hardware by purchasing
  products from Adafruit!

  Written by Limor Fried/Ladyada for Adafruit Industries.
  MIT license, all text above must be included in any redistribution
 ****************************************************/


#include <GxEPD2_BW.h>


GxEPD2_BW<GxEPD2_290_I6FD, GxEPD2_290_I6FD::HEIGHT> display(GxEPD2_290_I6FD(/*CS=D8*/ 0, /*DC=D3*/ 15, /*RST=D4*/ -1, /*BUSY=D2*/ -1)); // GDEW029I6FD



#define COLOR1 EPD_BLACK
#define COLOR2 EPD_RED

void setup() {
  display.setTextWrap(false);
  display.setRotation(3);
  display.init(115200);

  display.drawFastVLine(215,0,128,1);
  display.drawFastHLine(215,43,80,1);
  display.drawFastHLine(215,85,80,1);
  display.drawFastHLine(0,11,216,1);
  display.drawFastHLine(0,50,216,1);
  display.drawFastHLine(0,89,216,1);
  display.setFullWindow();
  display.display();

  delay(2000);

  
  display.setTextColor(1);
  display.setTextSize(1);
  display.setCursor(219, 2);
  display.print("Setpoint");
  display.setCursor(219, 46);
  display.print("Actual");
  display.setCursor(219, 88);
  display.print("Humidity");

  
  display.setTextSize(3);
  display.setCursor(219, 15);
  display.print("75.4");
  display.setCursor(219, 59);
  display.print("75.5");
  display.setCursor(231, 101);
  display.print("75%");

  
  display.setTextSize(1);
  display.setCursor(2, 2);
  display.print("Time: 10:07 Saturday, March 7 2022");
  display.display(1);
  delay(5000);

}

void loop() {
  //don't do anything!
}


void testdrawtext(const char *text, uint16_t color) {
  display.setCursor(0, 0);
  display.setTextColor(color);
  display.setTextWrap(true);
  display.print(text);
}

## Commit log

2021-08-13 Added Board libs
2021-08-14 Finished Schematic
    [Test Board.sch]
2021-08-15 Added BOM
    [Test Board.kicad_pcb, Test Board.sch]
2021-08-22 Finished Board Layout
    [BOM.xlsx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]
2021-09-06 Updated documentation
    [BOM.xlsx]
2021-09-13 Started working on firmware
    [Test Board.sch]
2021-11-07 Updated folder structure
    [BOM.xlsx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]
2021-11-13 Begin the process of a design shrink
    [BOM.xlsx, Test Board.sch]
2021-12-05 Started re-engineering board
    [BOM.xlsx, Test Board.kicad_pcb, Test Board.sch]
2022-01-14 Added E-Ink Display files
    Started making E-Ink Display footprints
    [Adafruit 2.9in eInk FeatherWing.brd, Adafruit 2.9in eInk FeatherWing.kicad_pcb, Adafruit 2.9in eInk FeatherWing.sch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]
2022-01-23 Finished E-Ink Footprint
    [Test Board.sch]
2022-01-24 Added Feather Symbol
    [Test Board.sch]
2022-02-08 Continued E-Ink display transition
    [BOM.xlsx, Test Board.sch]
2022-02-16 Finish Schematic for new PCB
    [BOM.xlsx, Test Board.kicad_pcb, Test Board.sch]
2022-02-16 Added KiCad Footprint for Feather
2022-07-06 More changes for surface mount design
    [Test Board.kicad_sch]
2022-07-08 Continue V2 Design
    [BOM.xlsx, Test Board.kicad_pcb, Test Board.kicad_sch]
2022-07-09 Continue board layout for v2 design
    [BOM.xlsx, Test Board.kicad_pcb, Test Board.kicad_sch]
2022-07-12 Finished board layout, updated readme
    [BOM.xlsx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]
2022-07-16 Started E-Ink interface programming
    [BOM.xlsx]

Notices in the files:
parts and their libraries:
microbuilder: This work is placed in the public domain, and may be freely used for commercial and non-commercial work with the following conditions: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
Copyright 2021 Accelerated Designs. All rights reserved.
